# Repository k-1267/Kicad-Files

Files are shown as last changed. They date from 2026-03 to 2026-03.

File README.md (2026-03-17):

# KiCad Projects (Nixie Tube Boards)

趣味の電子工作として作成した KiCad 基板設計データをまとめたリポジトリです。  
主にニキシー管（IN-18等）に関連する駆動基板およびマウント基板の設計データを格納しています。

---

## 1. Projects Overview

### 1) IN-18_MountingBoard
手に入るもので最大のニキシー管 **IN-18** のマウント基板です。
* **特徴:** 下記の駆動基板（Driving Board）と同サイズで設計しており、スタックして（重ねて）使用することが可能です。
* **必要部品:**
    * ニキシー管 IN-18 ×2
    * ニキシー管用ソケットピン ×28
    * ピンヘッダ (2x6) ×2

### 2) NixieTube_DrivingBoard
ニキシー管用の汎用駆動基板です。
* **制御方式:** 外部マイコン（ESP32やArduino等）と **I2C** で接続。
* **仕組み:** GPIOエキスパンダ **MCP23018** で制御信号を生成し、ニキシー管専用ドライバ **K155ID1** (SN74141互換) に入力して各カソード（数字）を選択・点灯させます。
* **拡張性:** 電流制限抵抗値を調整することで、IN-18 以外の管にも流用可能です。コロン（ネオンランプ）制御用の回路（MPSA42使用）も搭載しています。

---

## 2. Hardware Specifications

| 項目 | 内容 |
| :--- | :--- |
| **Logic Voltage** | 5V (K155ID1の動作電圧) |
| **Anode Voltage** | DC 170V (ニキシー管駆動用高電圧) |
| **Communication** | I2C (Address はADRピンのジャンパ設定により変更可能) |
| **Driver IC** | K155ID1 (Russian Nixie Driver) ×2 |
| **Expander IC** | MCP23018 ×1 |

---

## 3. Bill of Materials (BOM)

### Driving Board 主要部品
* **ICs:**
    * MCP23018 (I/O Expander) ×1
    * K155ID1 (Nixie Driver) ×2
* **Discrete Components:**
    * MPSA42 (高耐圧トランジスタ：コロン制御用) ×4
    * ニキシー管用電流制限抵抗 ×2
    * 各種抵抗（BおよびBE抵抗、プルアップ等）
* **Connectors:**
    * ピンヘッダ (1x3) ×3
    * ジャンパピン ×3

---

## 4. Repository Structure
```text
.
├── IN-18_MountingBoard/       # IN-18マウント基板プロジェクト
│   ├── IN-18_MountingBoard.kicad_pro
│   └── ...
├── NixieTube_DrivingBoard/    # 駆動基板プロジェクト
│   ├── NixieTube_DrivingBoard.kicad_pro
│   └── ...
└── images/                    # 回路図・外観プレビュー画像（※適宜追加）

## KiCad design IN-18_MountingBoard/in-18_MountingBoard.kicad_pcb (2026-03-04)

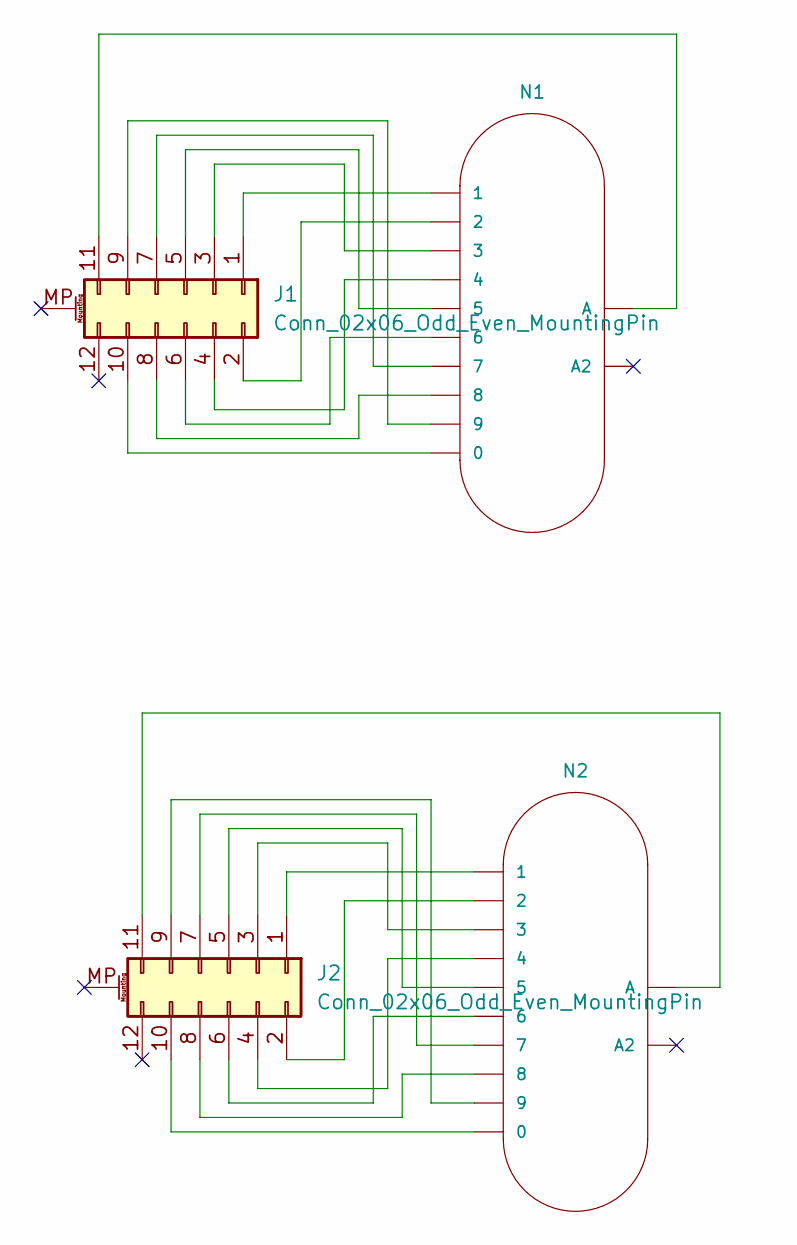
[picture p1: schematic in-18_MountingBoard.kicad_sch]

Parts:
J1, J2: Conn_02x06_Odd_Even_MountingPin; PinHeader_2x06_P2.54mm_Horizontal
N1, N2: IN-18; nixies-us-IN-18-DSUB

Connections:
unnamed: J1.1, N1.1
unnamed: J1.2, N1.2
unnamed: J1.3, N1.3
unnamed: J1.4, N1.4
unnamed: J1.5, N1.5
unnamed: J1.6, N1.6
unnamed: J1.7, N1.7
unnamed: J1.8, N1.8
unnamed: J1.9, N1.9
unnamed: J1.10, N1.0
unnamed: J1.11, N1.A
unnamed: J2.1, N2.1
unnamed: J2.2, N2.2
unnamed: J2.3, N2.3
unnamed: J2.4, N2.4
unnamed: J2.5, N2.5
unnamed: J2.6, N2.6
unnamed: J2.7, N2.7
unnamed: J2.8, N2.8
unnamed: J2.9, N2.9
unnamed: J2.10, N2.0
unnamed: J2.11, N2.A

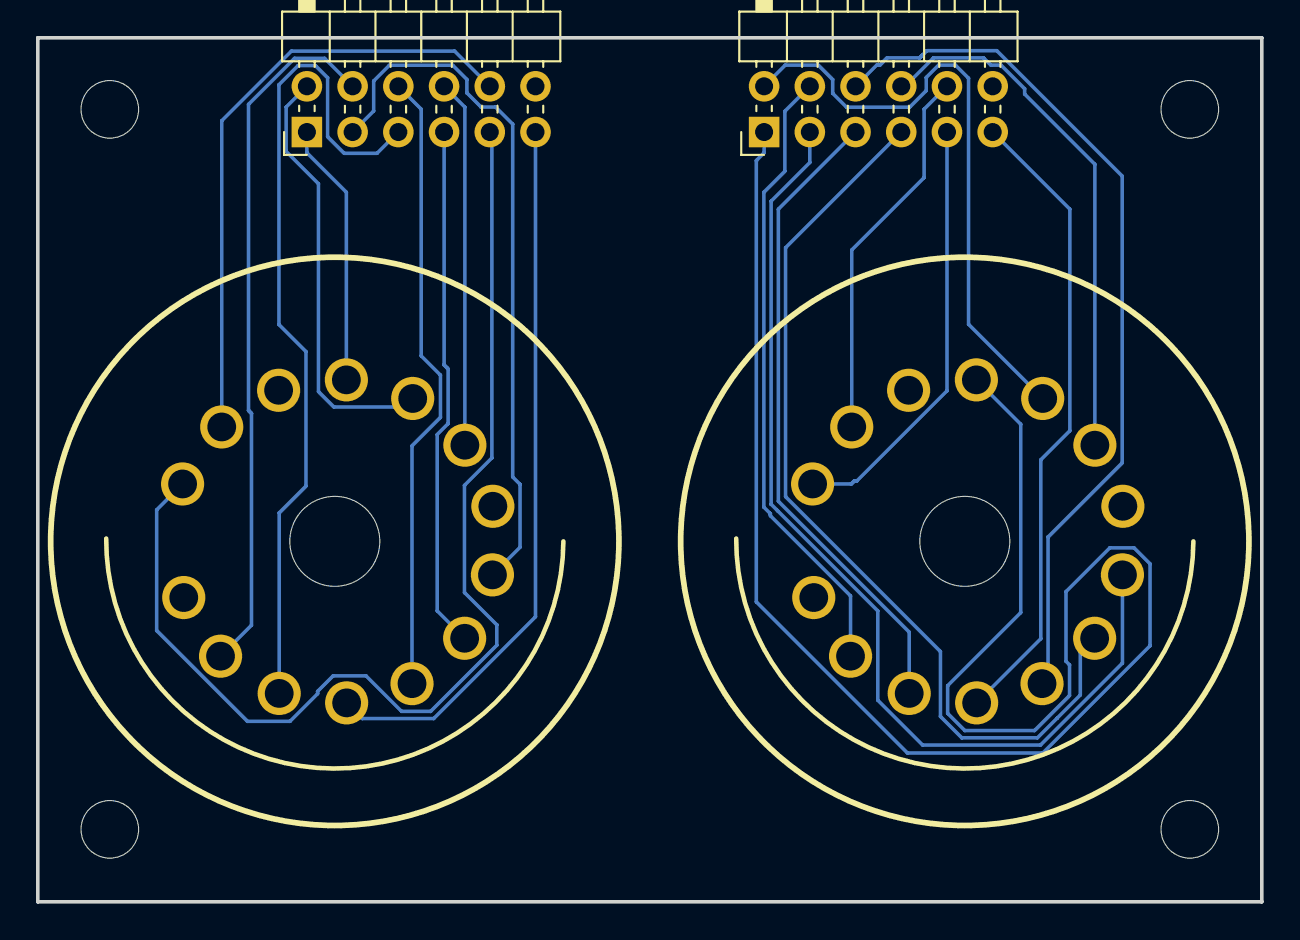
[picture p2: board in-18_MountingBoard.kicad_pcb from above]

Board: 2 copper layers, 68.0 x 48.0 mm, 8 parts (0 on the bottom side), 22 nets.

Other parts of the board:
REF1, REF2, REF3, REF4: MountingHole_3.2mm_M3

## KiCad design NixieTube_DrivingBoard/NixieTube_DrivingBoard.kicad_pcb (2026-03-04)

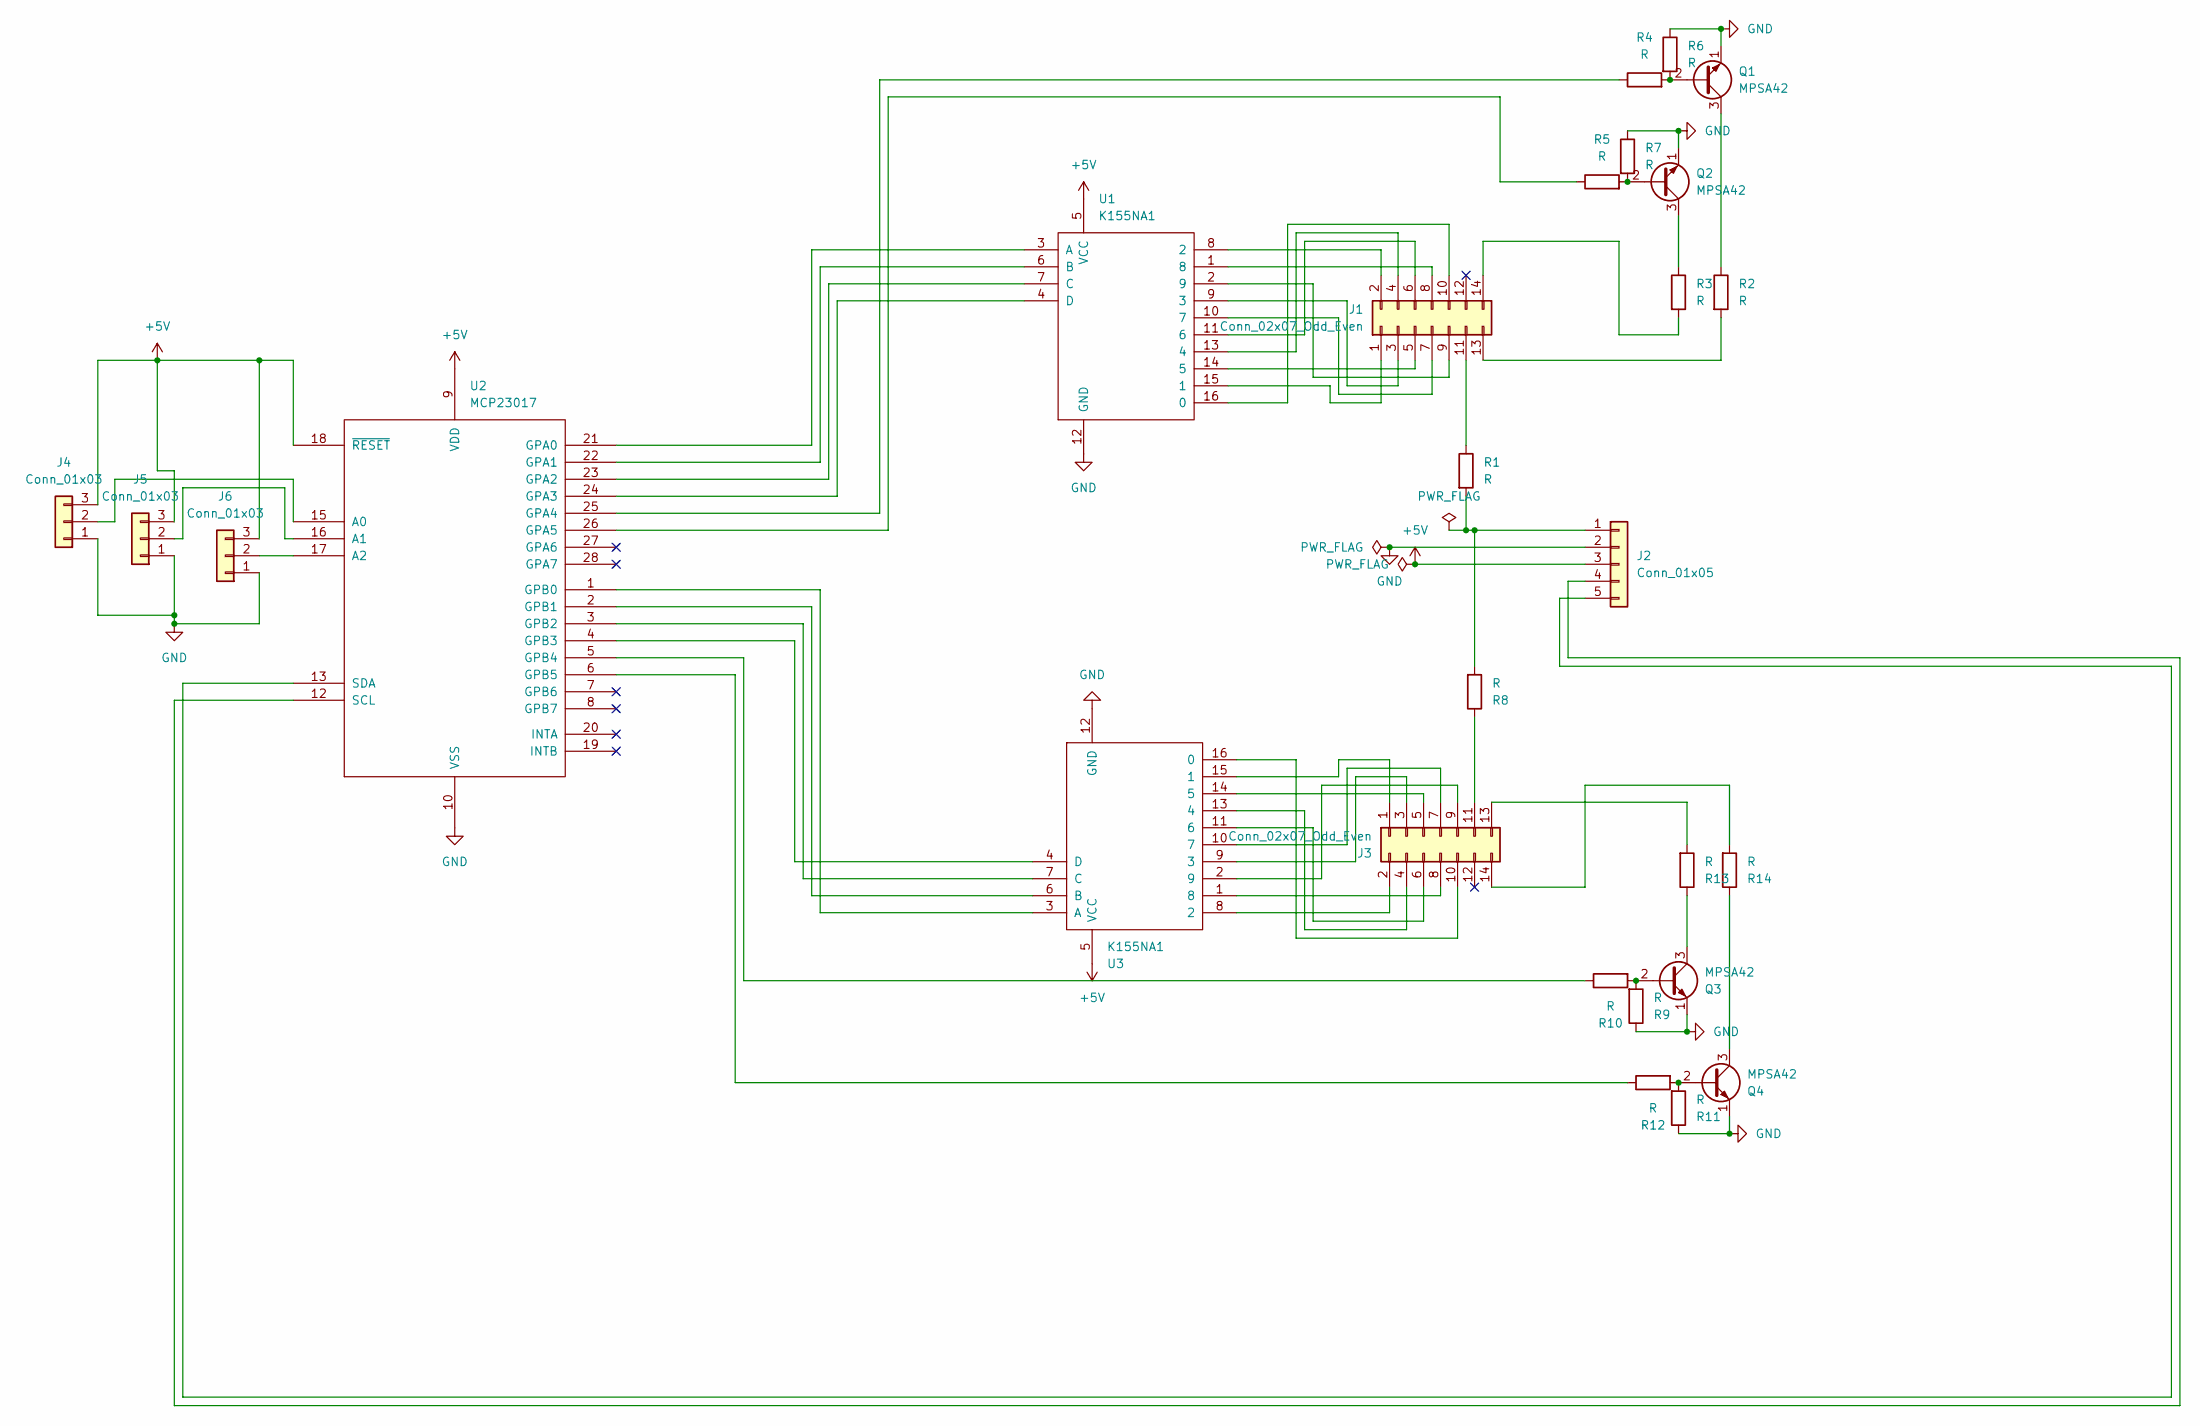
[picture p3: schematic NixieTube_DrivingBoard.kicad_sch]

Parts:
J1, J3: Conn_02x07_Odd_Even; PinHeader_2x07_P2.54mm_Vertical
J2: Conn_01x05; PinHeader_1x05_P2.54mm_Vertical
J4, J5, J6: Conn_01x03; PinHeader_1x03_P2.54mm_Vertical
Q1, Q2, Q3, Q4: MPSA42; TO-92_Inline
R1, R2, R3, R4, R5, R6, R7, R8, R9, R10, R11, R12, R13, R14: R; R_Axial_DIN0204_L3.6mm_D1.6mm_P5.08mm_Horizontal
U1, U3: K155NA1; DIP-16_W7.62mm_Socket
U2: MCP23017; DIP-28_W7.62mm_Socket

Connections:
+5V: J2.3, J4.3, J5.3, J6.3, U1.5 (VCC), U2.9 (VDD), U2.18 (~RESET), U3.5 (VCC)
GND: J2.2, J4.1, J5.1, J6.1, Q1.1 (E), Q2.1 (E), Q3.1 (E), Q4.1 (E), R6.1, R7.1, R9.1, R11.1, U1.12 (GND), U2.10 (VSS), U3.12 (GND)
unnamed: J1.1, U1.15 (1)
unnamed: J1.2, U1.8 (2)
unnamed: J1.3, U1.9 (3)
unnamed: J1.4, U1.13 (4)
unnamed: J1.5, U1.14 (5)
unnamed: J1.6, U1.11 (6)
unnamed: J1.7, U1.10 (7)
unnamed: J1.8, U1.1 (8)
unnamed: J1.9, U1.2 (9)
unnamed: J1.10, U1.16 (0)
unnamed: J1.11, R1.1
unnamed: J1.13, R2.2
unnamed: J1.14, R3.2
unnamed: J2.1, R1.2, R8.2
unnamed: J2.4, U2.12 (SCL)
unnamed: J2.5, U2.13 (SDA)
unnamed: J3.1, U3.15 (1)
unnamed: J3.2, U3.8 (2)
unnamed: J3.3, U3.9 (3)
unnamed: J3.4, U3.13 (4)
unnamed: J3.5, U3.14 (5)
unnamed: J3.6, U3.11 (6)
unnamed: J3.7, U3.10 (7)
unnamed: J3.8, U3.1 (8)
unnamed: J3.9, U3.2 (9)
unnamed: J3.10, U3.16 (0)
unnamed: J3.11, R8.1
unnamed: J3.13, R13.2
unnamed: J3.14, R14.2
unnamed: J4.2, U2.15 (A0)
unnamed: J5.2, U2.16 (A1)
unnamed: J6.2, U2.17 (A2)
unnamed: Q1.2 (B), R4.2, R6.2
unnamed: Q1.3 (C), R2.1
unnamed: Q2.2 (B), R5.2, R7.2
unnamed: Q2.3 (C), R3.1
unnamed: Q3.2 (B), R9.2, R10.2
unnamed: Q3.3 (C), R13.1
unnamed: Q4.2 (B), R11.2, R12.2
unnamed: Q4.3 (C), R14.1
unnamed: U1.3 (A), U2.21 (GPA0)
unnamed: U1.6 (B), U2.22 (GPA1)
unnamed: U1.7 (C), U2.23 (GPA2)
unnamed: U1.4 (D), U2.24 (GPA3)
unnamed: R4.1, U2.25 (GPA4)
unnamed: R5.1, U2.26 (GPA5)
unnamed: U2.1 (GPB0), U3.3 (A)
unnamed: U2.2 (GPB1), U3.6 (B)
unnamed: U2.3 (GPB2), U3.7 (C)
unnamed: U2.4 (GPB3), U3.4 (D)
unnamed: R10.1, U2.5 (GPB4)
unnamed: R12.1, U2.6 (GPB5)

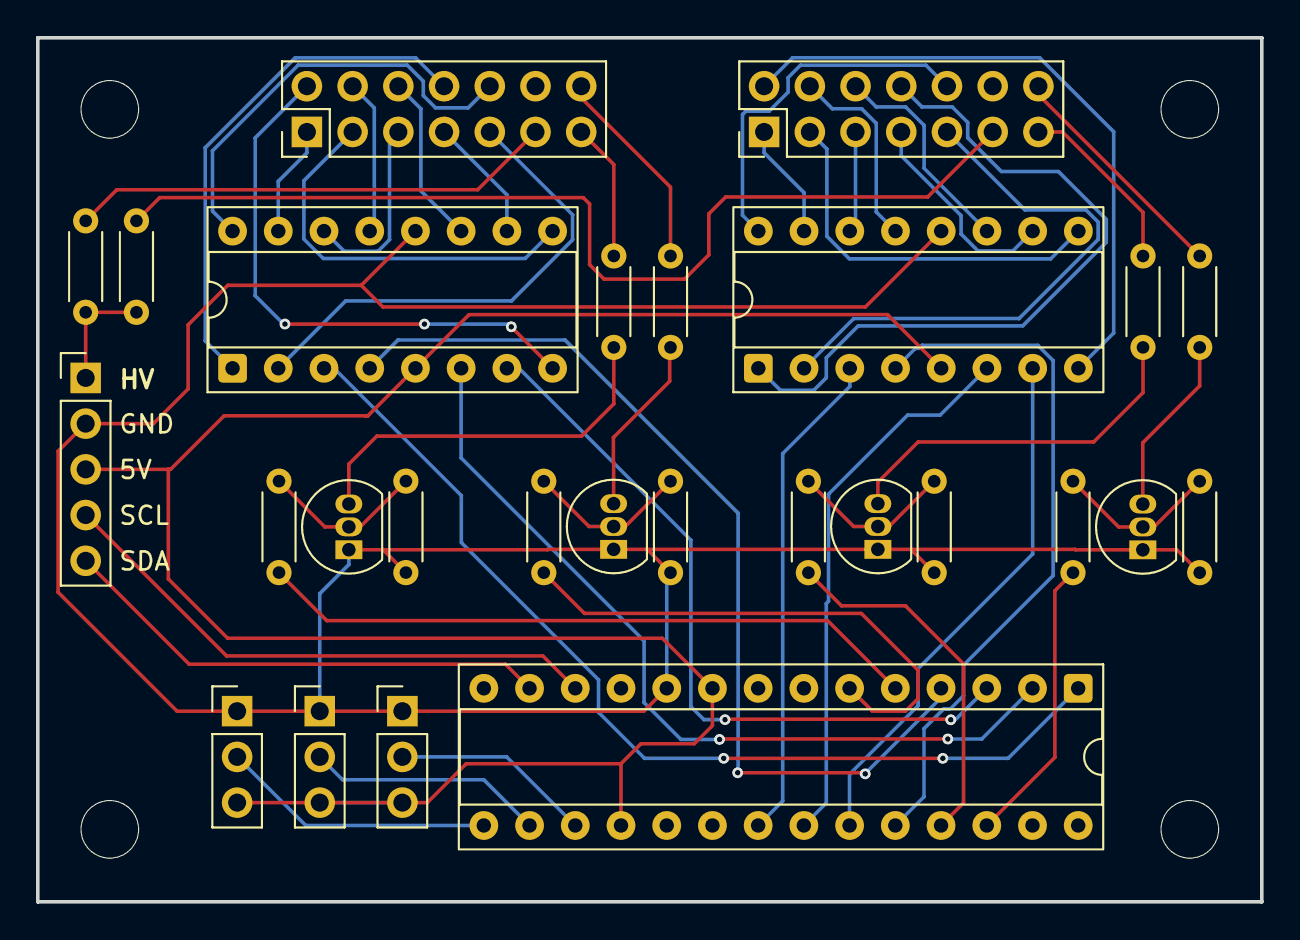
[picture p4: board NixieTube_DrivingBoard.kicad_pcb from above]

Board: 2 copper layers, 68.0 x 48.0 mm, 31 parts (0 on the bottom side), 54 nets.

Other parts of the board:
REF1, REF2, REF3, REF4: MountingHole_3.2mm_M3

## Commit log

2026-03-04 remove .DS_store
    [freerouting.dsn]
2026-03-04 Rename foldere
    [freerouting.dsn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]
